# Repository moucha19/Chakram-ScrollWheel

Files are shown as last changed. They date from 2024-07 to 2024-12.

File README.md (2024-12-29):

Chakram Scroll Wheel
===================

One day, scroll wheel on my Chakram X started misbehaving: sometimes scrolling in the wrong direction or not registering at all. After investigating, I concluded that the issue is most likely caused by a faulty encoder. Replacing it solved the problem, but I was no longer trusting the stock Kailh Red encoder, because the same issue was already reported online several times. To experiment with potentially higher-quality encoders without risking damage to the original part, I decided to recreate the entire scroll wheel PCB, staying as true to the original schematic and components as possible.

## Compatibility

| **Model** | **Tested** | **Notes** |
| --- | --- | --- |
| Asus Chakram X | ✅ | Fully functional |
| Asus Chakram X Origin | ❓ | Untested, likely compatible |
| Asus Chakram | ❓ | Untested, compatibility unknown |
| Asus Chakram Core | ❓ | Untested, compatibility unknown |

## Bill of materials

| Designator | Footprint | Part link |
|---|---|---|
| D1,D2,D3,D4,D6,D7  | SMD 0402 ESD protection | [C1974929](https://www.lcsc.com/product-detail/C1974929.html ) |
| D5 | *RGB LED daughterboard* | [C2843813](https://www.lcsc.com/product-detail/C2843813.html) |
| EN1 | Rotary encoder, 9mm height | [688-EC10E1220501](https://mouser.com/ProductDetail/688-EC10E1220501) |
| J1 | HRS(Hirose) FH12-8S-0.5SH(55) | [C597995](https://www.lcsc.com/product-detail/C597995.html) |
| R1,R2 | 1k SMD 0402 Resistor | [C11702](https://www.lcsc.com/product-detail/C11702.html) |
| SW1 | EVQ-P0 series tactile switch  | [C395225](https://www.lcsc.com/product-detail/C395225.html) |
 
Most of the parts listed are suggestions, and there are many compatible alternatives. This is particularly true for the encoder — selecting one depends on your personal preference, as different models vary in terms of tactility and scrolling force. I recommend starting with [this Reddit post](https://www.reddit.com/r/MouseReview/comments/18x4q6y/what_are_they_and_how_to_choose_mouse_encoders/) first, to see what's out there. 

However, regardless of the encoder you choose, **always use the 1k resistors** specified in the BOM. Do not use the resistor value mentioned in the encoder’s datasheet.

## Assembly

The board matches the original exactly, so simply connect the cable and screw it in.

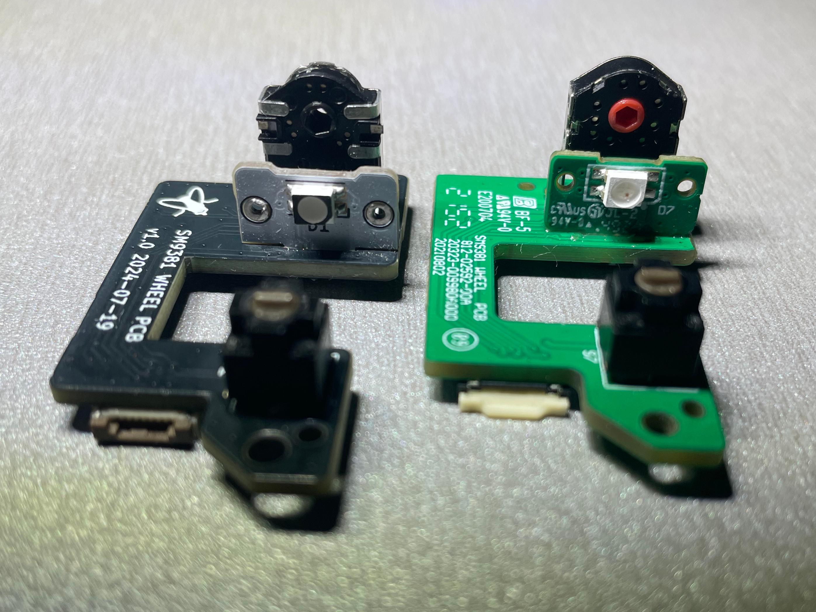
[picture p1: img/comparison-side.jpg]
Side-by-side comparison

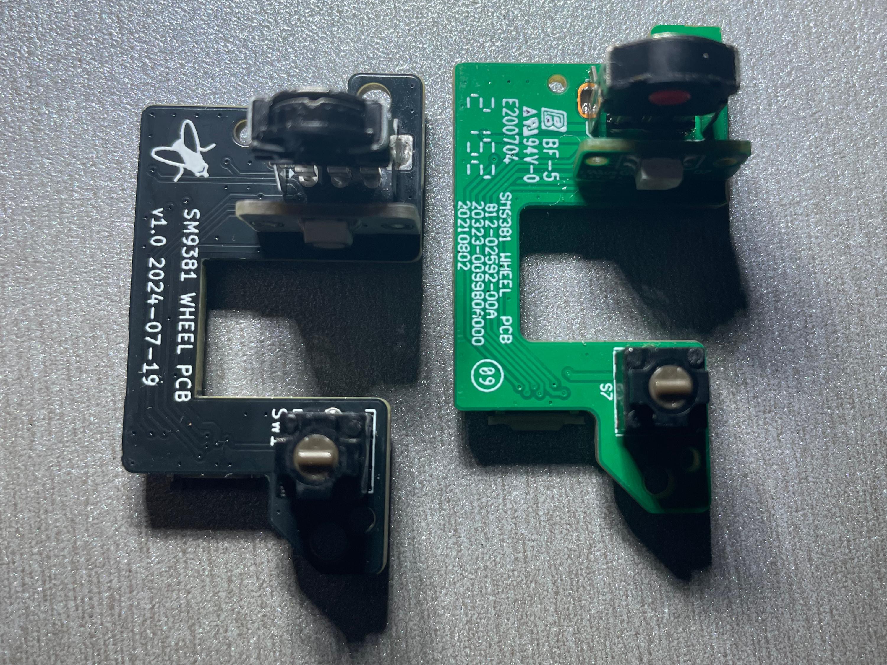
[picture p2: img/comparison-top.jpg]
Top-view comparison

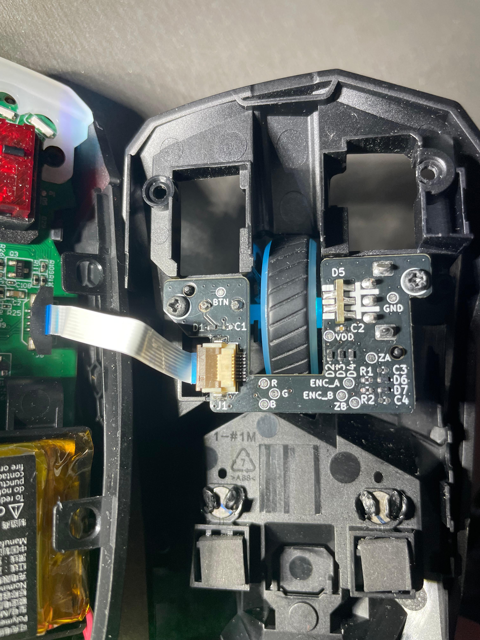
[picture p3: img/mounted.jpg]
Mounted board


#### Disclaimer

*This project is not affiliated with or endorsed by Asus. Use this design at your own risk. Ensure you follow proper safety protocols when handling electronic components and soldering.*

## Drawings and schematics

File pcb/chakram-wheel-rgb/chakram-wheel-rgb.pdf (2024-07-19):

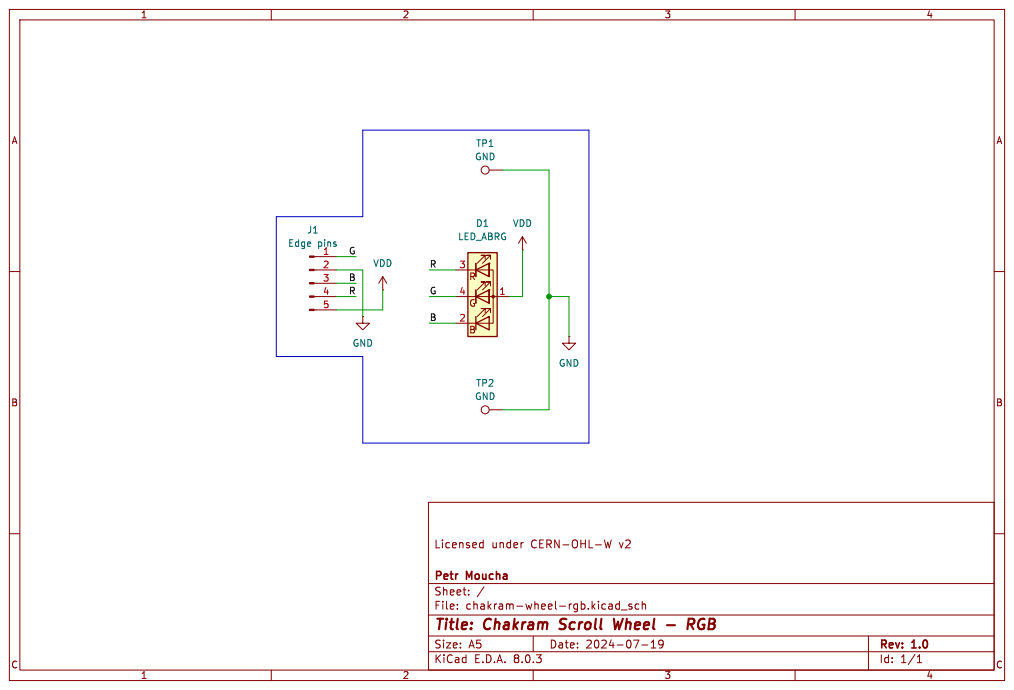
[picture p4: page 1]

Id: 1/1 Title: Chakram Scroll Wheel - RGB

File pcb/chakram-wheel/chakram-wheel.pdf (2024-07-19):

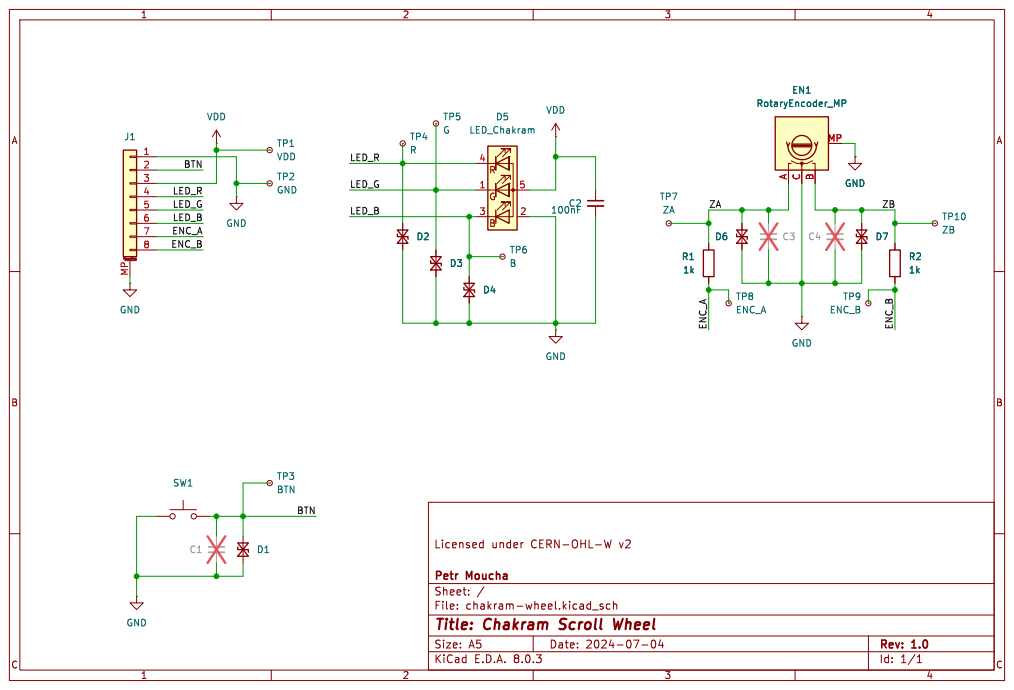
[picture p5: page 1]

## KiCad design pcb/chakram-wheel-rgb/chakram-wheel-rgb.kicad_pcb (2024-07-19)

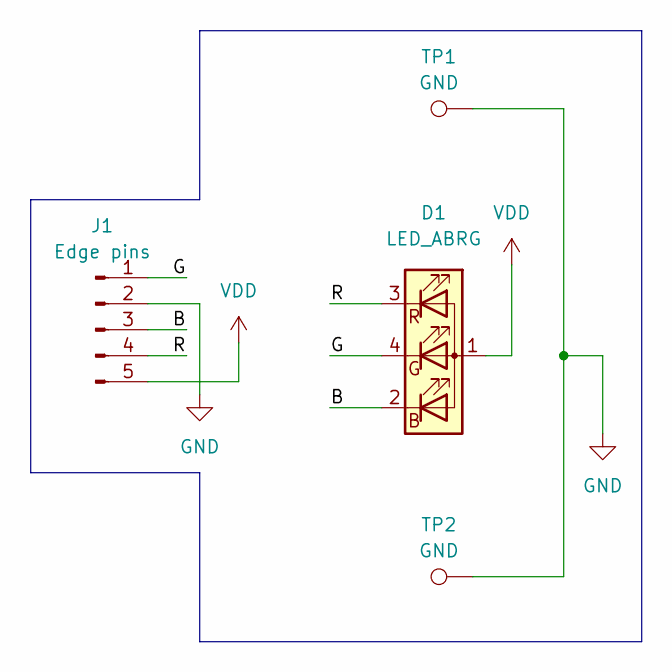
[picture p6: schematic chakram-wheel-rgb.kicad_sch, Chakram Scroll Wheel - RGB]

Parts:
D1: LED_ABRG; LED_RGB_Wuerth-PLCC4_3.2x2.8mm_150141M173100
J1: Edge pins; LED_Chakram_Edge
TP1, TP2: GND; TestPoint_THTPad_D2.0mm_Drill1.0mm

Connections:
/B: D1.2 (BK), J1.3
/G: D1.4 (GK), J1.1
/R: D1.3 (RK), J1.4
GND: J1.2, TP1.1, TP2.1
VDD: D1.1 (A), J1.5

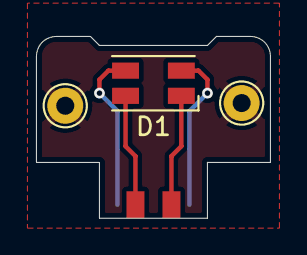
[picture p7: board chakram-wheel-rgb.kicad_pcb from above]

Board: 2 copper layers, 13.0 x 10.1 mm, 4 parts (1 on the bottom side), 5 nets.

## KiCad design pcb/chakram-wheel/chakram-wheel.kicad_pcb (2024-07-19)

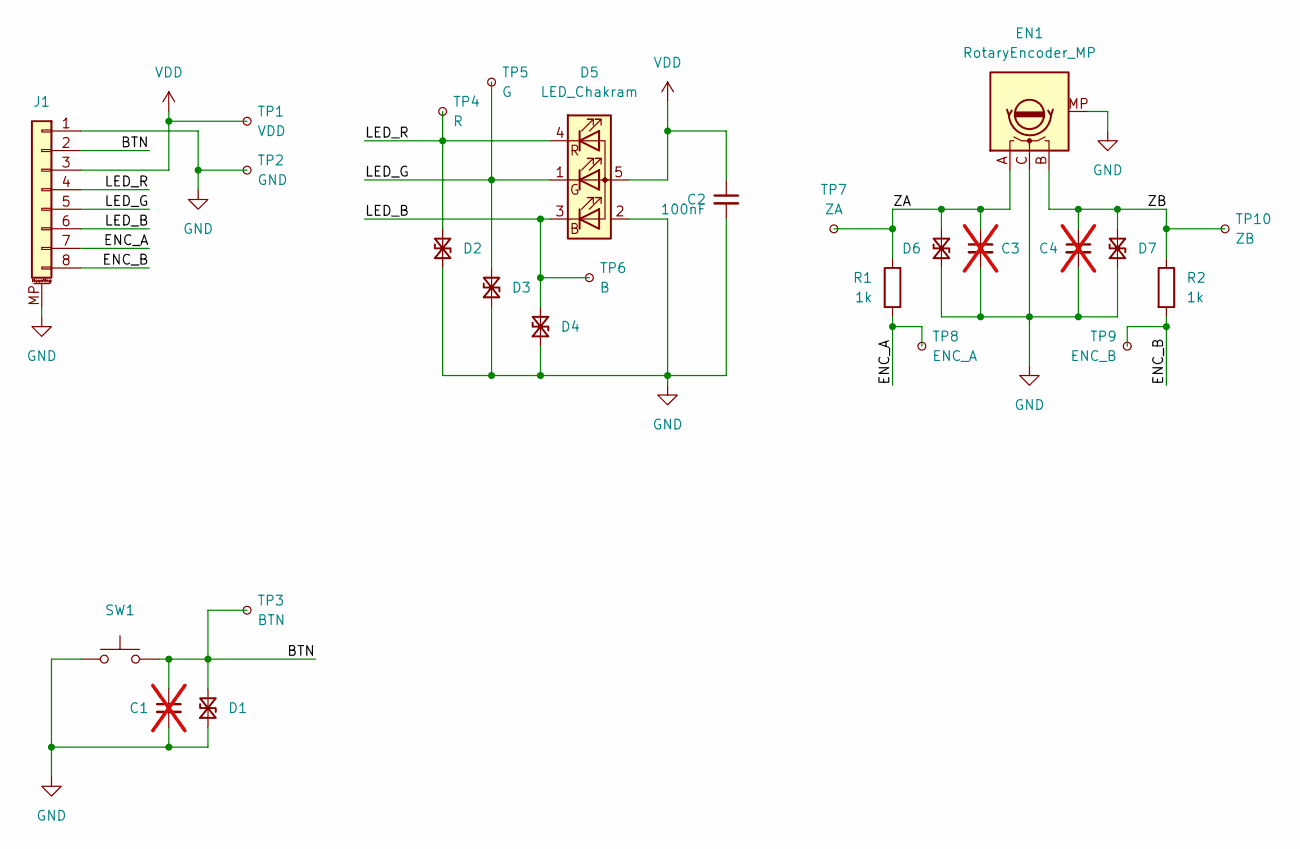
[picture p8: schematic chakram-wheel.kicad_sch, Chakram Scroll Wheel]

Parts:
C1, C3, C4: C_0402_1005Metric; not fitted
C2: 100nF; C_0402_1005Metric
D1, D2, D3, D4, D6, D7: D_TVS_Small; D_0402_1005Metric
D5: LED_Chakram
EN1: RotaryEncoder_MP; RotaryEncoder_Alps_EC10E
J1: FPC Connector; Hirose_FH12-8S-0.5SH_1x08-1MP_P0.50mm_Horizontal
R1, R2: 1k; R_0402_1005Metric
SW1: SW_Push_EVQP0
TP1: VDD; TestPoint_Pad_D1.0mm
TP2: GND; TestPoint_Pad_D1.0mm
TP3: BTN; TestPoint_Pad_D1.0mm
TP4: R; TestPoint_Pad_D1.0mm
TP5: G; TestPoint_Pad_D1.0mm
TP6: B; TestPoint_Pad_D1.0mm
TP7: ZA; TestPoint_Pad_D1.0mm
TP8: ENC_A; TestPoint_Pad_D1.0mm
TP9: ENC_B; TestPoint_Pad_D1.0mm
TP10: ZB; TestPoint_Pad_D1.0mm

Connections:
/BTN: C1.1, D1.2 (A2), J1.2, SW1.2, TP3.1
/ENC_A: J1.7, R1.2, TP8.1
/ENC_B: J1.8, R2.2, TP9.1
/LED_B: D4.2 (A2), D5.3 (BK), J1.6, TP6.1
/LED_G: D3.2 (A2), D5.1 (GK), J1.5, TP5.1
/LED_R: D2.2 (A2), D5.4 (RK), J1.4, TP4.1
/ZA: C3.1, D6.2 (A2), EN1.A, R1.1, TP7.1
/ZB: C4.1, D7.2 (A2), EN1.B, R2.1, TP10.1
GND: C1.2, C2.2, C3.2, C4.2, D1.1 (A1), D2.1 (A1), D3.1 (A1), D4.1 (A1), D5.2 (EP), D6.1 (A1), D7.1 (A1), EN1.C, EN1.MP, J1.1, J1.MP (MountPin), SW1.1, TP2.1
VDD: C2.1, D5.5 (A), J1.3, TP1.1

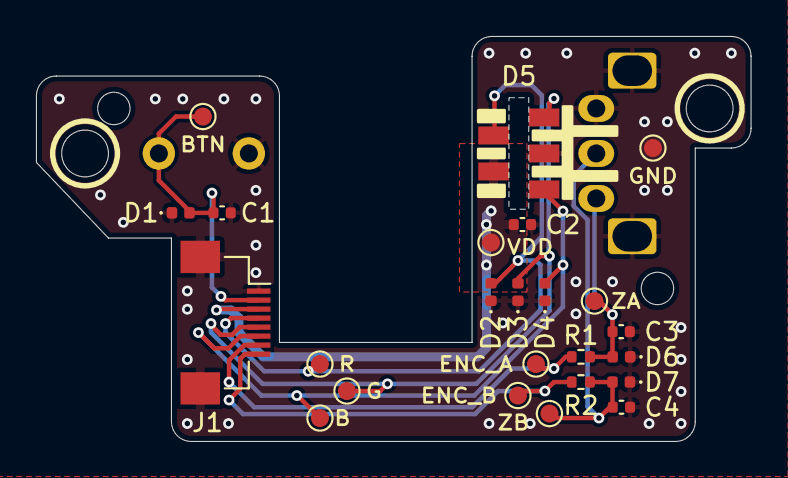
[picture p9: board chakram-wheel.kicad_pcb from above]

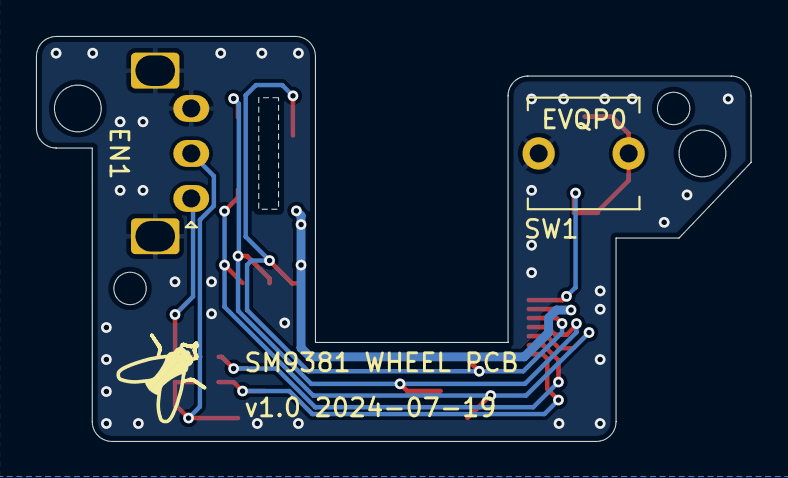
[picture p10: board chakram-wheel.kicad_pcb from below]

Board: 2 copper layers, 39.7 x 22.5 mm, 26 parts (2 on the bottom side), 10 nets.

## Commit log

2024-07-04 Updated hole and component positions
    [Chakram-ScrollWheel.kicad_pcb]
2024-07-04 Improved encoder symbol to also include MP pins and connected them to GND
    [Chakram-ScrollWheel.kicad_pcb, Chakram-ScrollWheel.kicad_sch]
2024-07-04 Added testpoints
    [Chakram-ScrollWheel.kicad_pcb, Chakram-ScrollWheel.kicad_sch]
2024-07-04 Positioned all test points
    [Chakram-ScrollWheel.kicad_pcb, Chakram-ScrollWheel.kicad_sch]
2024-07-04 Routed all signals
    [Chakram-ScrollWheel.kicad_pcb]
2024-07-04 Updated pad type for LED slot pads
    [Chakram-ScrollWheel.kicad_pcb]
2024-07-04 Added button part name to silkscreen
    [Chakram-ScrollWheel.kicad_pcb]
2024-07-04 Added more silkscreen elements, minor cleanups
    [Chakram-ScrollWheel.kicad_pcb, Chakram-ScrollWheel.kicad_sch]
2024-07-04 Added ground stitching
    [Chakram-ScrollWheel.kicad_pcb]
2024-07-04 Adjusted encoder MP pad position and size
    [Chakram-ScrollWheel.kicad_pcb]
2024-07-04 Rounded corners
    [Chakram-ScrollWheel.kicad_pcb]
2024-07-04 Fixed swapped ENC_A and ENC_B signals on J1
    [Chakram-ScrollWheel.kicad_pcb, Chakram-ScrollWheel.kicad_sch]
2024-07-18 Adjusted RGB slot dimensions, added RGB board
    [chakram-wheel-rgb.kicad_pcb, chakram-wheel-rgb.kicad_sch, chakram-wheel.kicad_pcb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]
2024-07-19 Added generated schematics, updated silkscreen and RGB board shape
    [chakram-wheel-rgb.kicad_pcb, chakram-wheel.kicad_pcb, chakram-wheel.kicad_sch]
2024-07-19 Added fabrication output settings
    [chakram-wheel-rgb.kicad_pcb, chakram-wheel.kicad_pcb]

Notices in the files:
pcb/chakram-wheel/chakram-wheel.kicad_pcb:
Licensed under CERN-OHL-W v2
